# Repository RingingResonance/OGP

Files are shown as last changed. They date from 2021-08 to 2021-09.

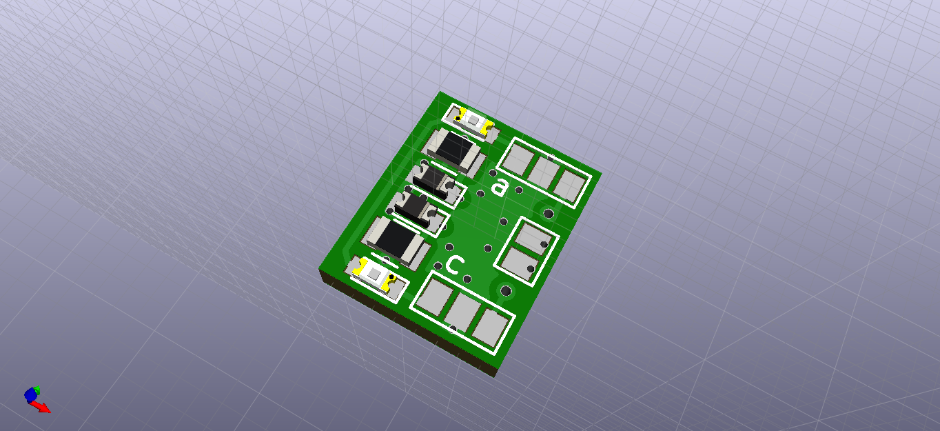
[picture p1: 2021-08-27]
pickups/3Drender.png

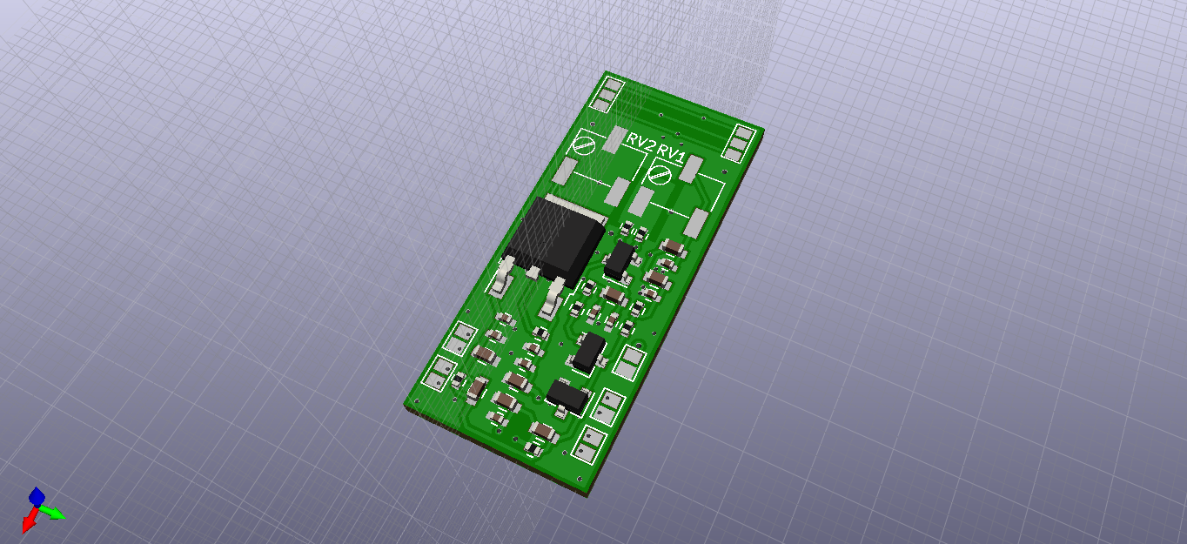
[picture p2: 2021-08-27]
powersupply/3Drender.png

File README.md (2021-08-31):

# OGP

This Optical pickup is being designed so that it can be used on any string instrument while being minimally intrusive and remaing flexible.
It has a differential sensor array for each string, each with it's own circuit board. The IR LEDs are modulated at 500khz. The Demodulation boards are designed to
reject all other signals except the 500khz differential signal from the sensors in order to reject environment noise. 
Additionally, an IR passthrough filter over the sensors may be added for further noise rejection, or a beveled cover may be added over the top of the strings.
This cover needs to absorb and deflect all light coming from the IR LEDs because the circuit relies on no reflected light 
coming back to the sensors except what is being reflected by the strings. It needs to be a light trap on the inside of some sort.

This design is still being tested and refined.
If you have any ideas, or are more experenced in electronics, or if you see flaws in my design please feel free to reach out to me or modify the circuit to your will.
Music should be free for anyone to make and therfore I'm providing this circuit FREE for anyone to build, BUT NOT TO SELL, 
and without any warranty that this circuit will work for your needs or work at all.

It's my design, give credit where it's due. Thank you. 
I am intested in hearing any and all feedback about this circuit and any interesting applications it's been fitted to. ;-)

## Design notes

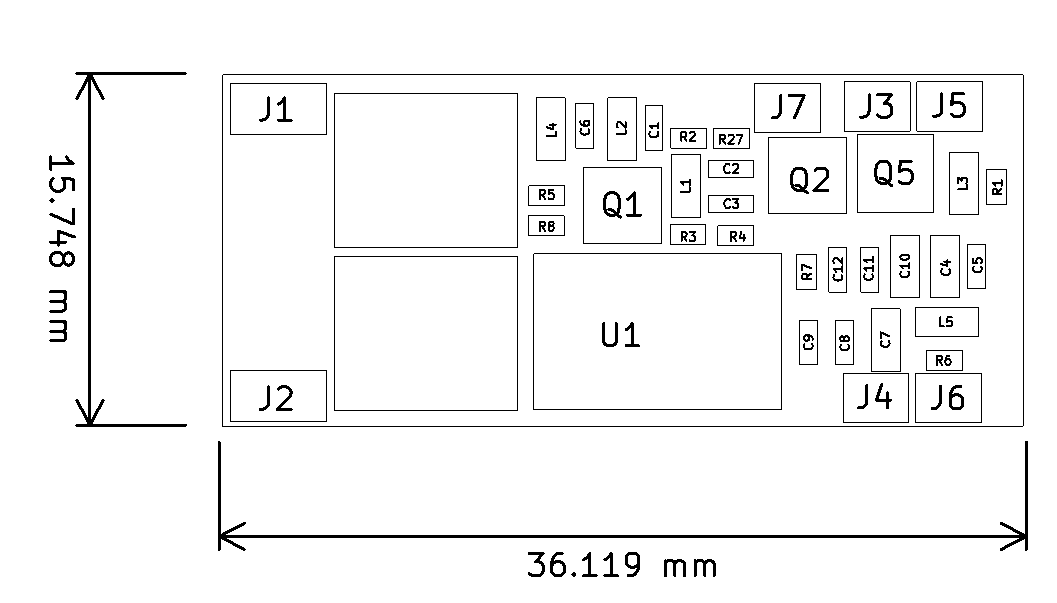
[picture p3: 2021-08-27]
powersupply/BoardLayout.png

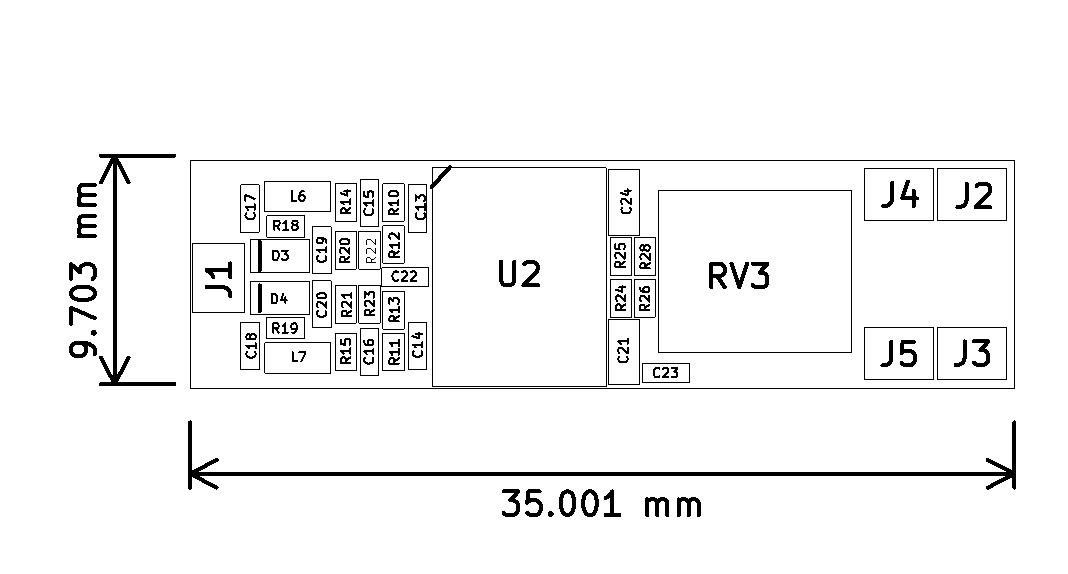
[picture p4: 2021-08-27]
demodulators/BoardLayout.png

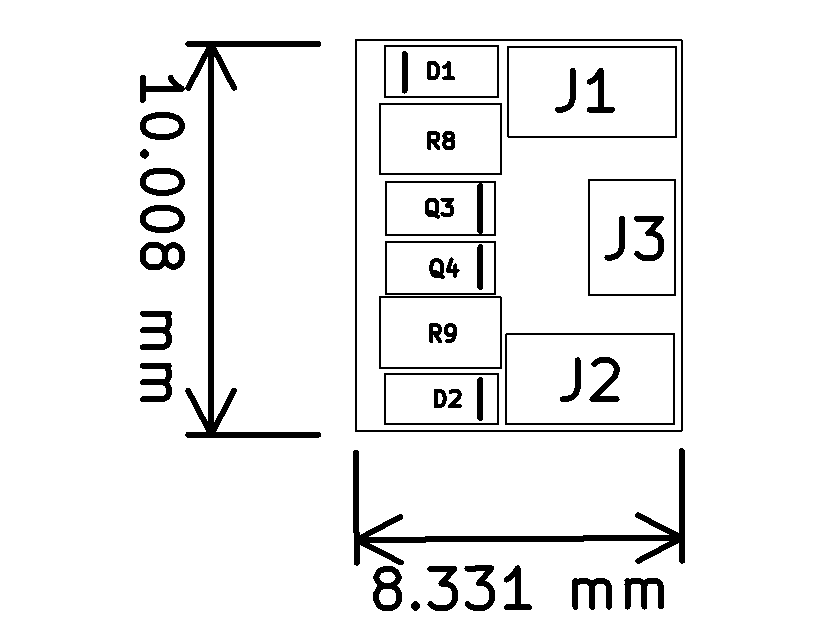
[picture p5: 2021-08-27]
pickups/BoardLayout.png

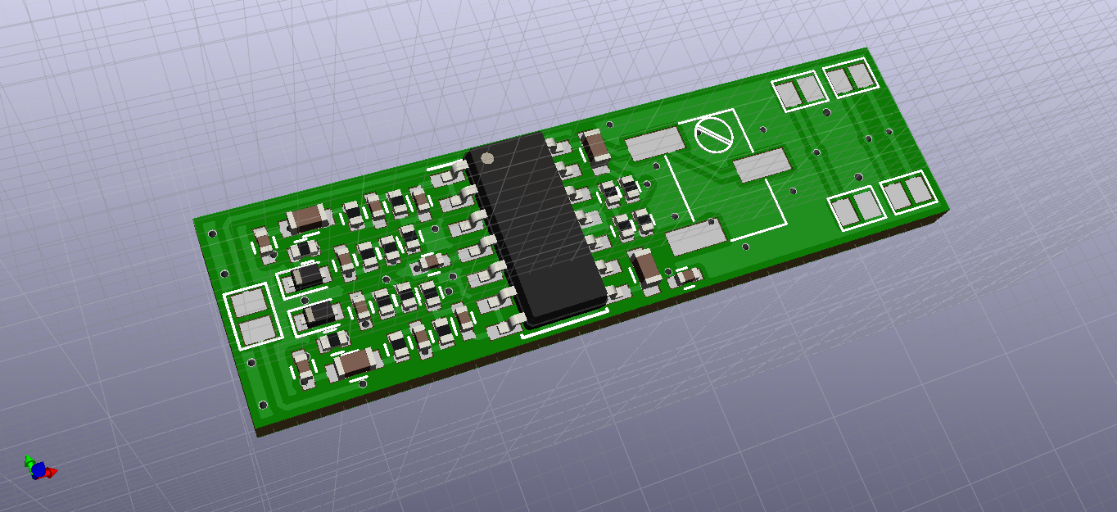
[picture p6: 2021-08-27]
demodulators/3Drender.png

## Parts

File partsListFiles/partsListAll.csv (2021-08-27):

Quantity | Part Number | Manufacturer Part Number | Description
2 | 1276-1538-1-ND | CL05B223KP5NNNC | CAP CER 0.022UF 10V X7R 0402
5 | 1276-1067-1-ND | CL05A105KO5NNNC | CAP CER 1UF 16V X5R 0402
15 | 1276-1871-1-ND | CL10A106MP8NNNC | CAP CER 10UF 10V X5R 0603
8 | 1276-6720-1-ND | CL05B104KA5NNNC | CAP CER 0.1UF 25V X7R 0402
3 | BC817-40FDICT-ND | BC817-40-7-F | TRANS NPN 45V 500MA SOT23-3
26 | RR05P300DCT-ND | RR0510P-301-D | RES SMD 300 OHM 0.5% 1/16W 0402
2 | RG10P2.0KBCT-ND | RG1005P-202-B-T5 | RES SMD 2K OHM 0.1% 1/16W 0402
3 | 2037-PFR05S-201-FNHCT-ND | PFR05S-201-FNH | RES SMD 200 OHM 1% 1/16W 0402
1 | P240DECT-ND | ERA-2AED241X | RES SMD 240 OHM 0.5% 1/16W 0402
49 | YAG1234CT-ND | RT0402FRE071KL | RES SMD 1K OHM 1% 1/16W 0402
1 | 3361P-102GLFCT-ND | 3361P-1-102GLF | TRIMMER 1K OHM 0.5W GW TOP ADJ
1 | 3361P-502GLFCT-ND | 3361P-1-502GLF | TRIMMER 5K OHM 0.5W GW TOP ADJ
1 | LM317MABDTG-ND | LM317MABDTG | IC REG LINEAR POS ADJ 500MA DPAK
12 | 1497-1367-1-ND | XZTNI53W-1 | EMITTER IR 940NM 50MA SMD
12 | QSB363GRCT-ND | QSB363GR | SENSOR PHOTO 940NM TOP VIEW 2SMD
12 | RNCP0805FTD10K0CT-ND | RNCP0805FTD10K0 | RES 10K OHM 1% 1/4W 0805
12 | 1514-CMOSH-4ETRPBFREECT-ND | CMOSH-4E TR PBFREE | DIODE SCHOTTKY 40V 200MA SOD523
17 | 445-6389-1-ND | MLZ1608M100WT000 | FIXED IND 10UH 250MA 1.05OHM SMD
12 | RG10P51KBCT-ND | RG1005P-513-B-T5 | RES SMD 51K OHM 0.1% 1/16W 0402
12 | YAG2305CT-ND | RT0402BRE0710KL | RES SMD 10K OHM 0.1% 1/16W 0402
6 | 3361P-1-504GLFCT-ND | 3361P-1-504GLF | TRIMMER 500K OHM 0.5W GW TOP ADJ
6 | AD8668ARZ-ND | AD8668ARZ | IC OPAMP GP 4 CIRCUIT 14SOIC
24 | 1276-1489-1-ND | CL05B102JB5NNNC | CAP CER 1000PF 50V X7R 0402
12 | 1276-1499-1-ND | CL05B103KB5NFNC | CAP CER 10000PF 50V X7R 0402
18 | 1276-1562-1-ND | CL05B392KB5NNNC | CAP CER 3900PF 50V X7R 0402

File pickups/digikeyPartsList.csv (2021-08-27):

Index | Quantity | Part Number | Manufacturer Part Number | Description | Customer Reference | Available | Backorder | Unit Price | Extended Price USD
1 | 2 | 1497-1367-1-ND | XZTNI53W-1 | EMITTER IR 940NM 50MA SMD |  | 2 | 0 | 0.53000 | 1.06
2 | 2 | QSB363GRCT-ND | QSB363GR | SENSOR PHOTO 940NM TOP VIEW 2SMD |  | 2 | 0 | 0.53000 | 1.06
3 | 2 | RNCP0805FTD10K0CT-ND | RNCP0805FTD10K0 | RES 10K OHM 1% 1/4W 0805 |  | 2 | 0 | 0.10000 | 0.20

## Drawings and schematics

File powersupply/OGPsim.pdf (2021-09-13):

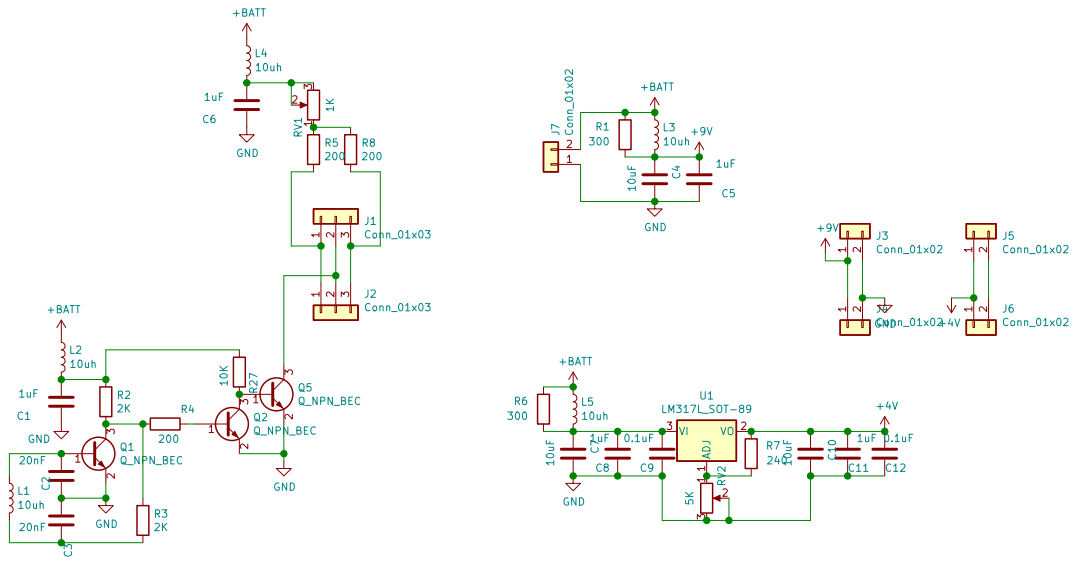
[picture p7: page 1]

Id: 1/1 Title: File: OGPsim.sch Sheet: /

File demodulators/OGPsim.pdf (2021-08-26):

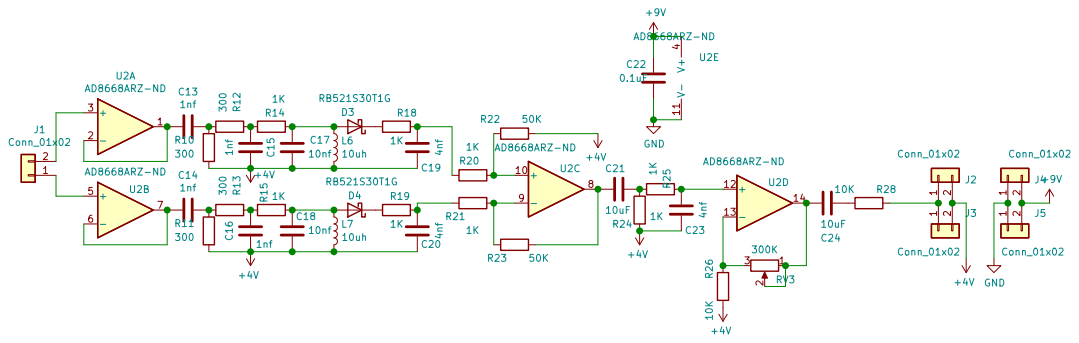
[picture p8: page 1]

Id: 1/1 Title: File: OGPsim.sch Sheet: /

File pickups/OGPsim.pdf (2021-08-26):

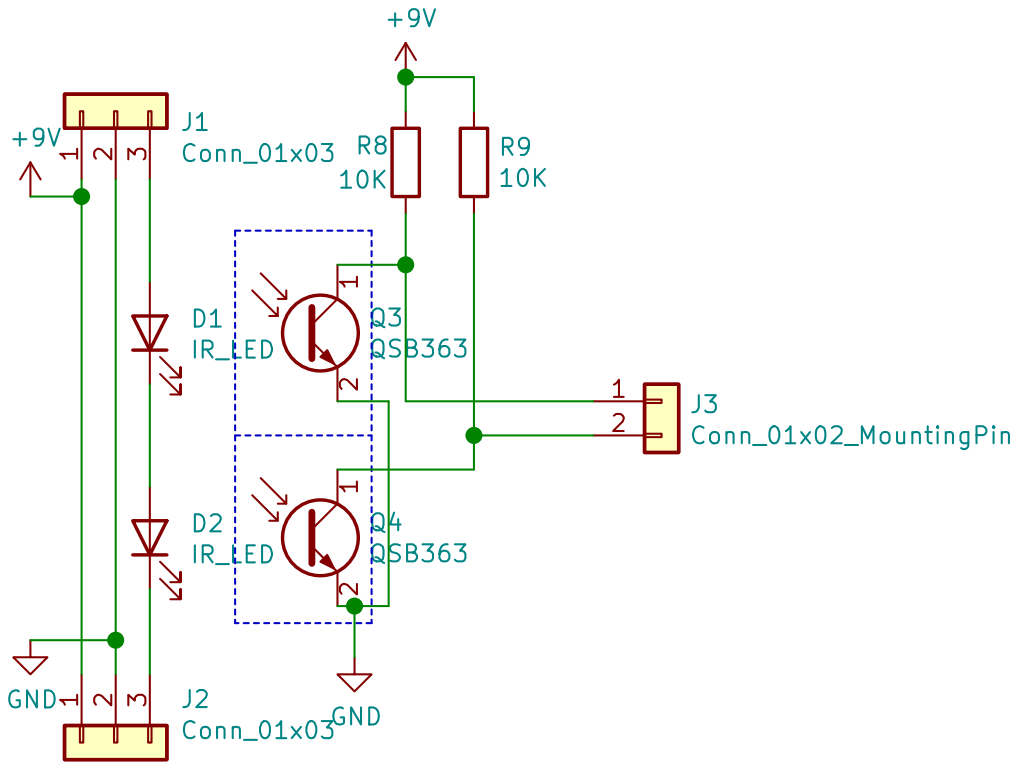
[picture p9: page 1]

Id: 1/1 Title: File: OGPsim.sch Sheet: / 1

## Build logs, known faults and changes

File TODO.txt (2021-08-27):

DONE, 1: Organize and add silkscreen markings.

2: Test all functions of circuit.

3: Design analog postprocessing board that performs an absolute value function on each individual string waveform so that output will sound more like a normal pickup.

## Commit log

2021-08-24 Initial Commit of DEPRECATED DESIGN
    [OGP-B_Cu.gbr, OGP-B_Mask.gbr, OGP-Edge_Cuts.gbr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]
2021-08-24 Created PDF schematic.
2021-08-26 Switching over to new design.
    [OGP-B_Cu.gbr, OGP-B_Mask.gbr, OGP-Edge_Cuts.gbr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]
2021-08-26 Updated Schematic page size and added schematic files in PDF format.
    [OGPsim.sch]
2021-08-26 Removed 1 ohm resistors as it was only used for simulating parasitic resistance in tank circuit.
    [OGPsim.kicad_pcb, OGPsim.sch]
2021-08-26 Added Solder Pads To Demodulator Board
    [OGPsim.kicad_pcb, OGPsim.sch]
2021-08-26 Added solder pads to pickup and adjusted placement of solder pads on demodulator.
    [OGPsim.kicad_pcb, OGPsim.sch]
2021-08-26 Updated power supply board layout.
    [OGPsim.kicad_pcb, OGPsim.sch]
2021-08-26 Updated power supply board and schematic to have solderable pads.
    [OGPsim.kicad_pcb, OGPsim.sch]
2021-08-27 Added TODO list. Added solder pads for power input on power supply board.
    [OGPsim.kicad_pcb, OGPsim.sch]
2021-08-27 Cleaned up silk screen layers and moved part REFs to UserDrawings. Made PNG image file of part REFs for Power Supply and Pickup Boards.
    [OGPsim-B_Cu.gbr, OGPsim-B_Mask.gbr, OGPsim-B_Paste.gbr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]
2021-08-27 Finished organizing Part REFs layout and Updated Layout Images. Finished generating GERBER files.
    [OGPsim-B_Cu.gbr, OGPsim-B_Mask.gbr, OGPsim-Edge_Cuts.gbr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]
2021-08-27 Updated TODO file.
    [OGPsim-B_Paste.gbr, OGPsim-B_SilkS.gbr, OGPsim-F_Paste.gbr]
2021-08-27 Added 3D renders of boards.
2021-08-27 Added name and date to silkscreen on all boards. Sending design to PCB fab house tonight!
    [OGPsim-B_Cu.gbr, OGPsim-B_Mask.gbr, OGPsim-Edge_Cuts.gbr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]
2021-08-27 Added digikey parts list. Had to substitute some parts due to lack of stock at digikey.
    [OGPsim.sch, digikeyPartsList.csv, digikeyPartsList.xlsx]
2021-08-27 Organized Parts Lists for full build and sample builds. Included digikey parts list.
    [demodulatorPartsAll.csv, digikeyPartsListAll.csv, digikeyPartsListAll.xlsx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]
2021-09-13 Fixed LM317 having wrong pinout in schematic and on board layout.
    [OGPsim-B_Cu.gbr, OGPsim-B_Mask.gbr, OGPsim-Edge_Cuts.gbr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]
